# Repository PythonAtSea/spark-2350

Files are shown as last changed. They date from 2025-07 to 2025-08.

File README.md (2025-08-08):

# spark!2350

A badge of a Cerberus and a raccoon laughing together, with the text 'HIGHWAY' and 'HACK CLUB' beside them. (https://highway.hackclub.com)

## What is this?

The spark!2350 is a RP2350 based microcontroller that has a RM2 chip for BLE and WiFi. It also has a LiPo battery charger, as it is designed for use in mireless keyboards. It also has a user accesable NeoPixel, and a variable charge rate. 

## Why?

I saw the release of the RM2 and I immediatly knew I wanted to make something with it. I've always thought the nice!nano was cool, so I kinda made that, although this is designed for maximum GPIO availibility, not small size. 









made with <3 and insanity.

## BOM

| Name | Link | Price |
|---|---|---|
| RPI RM2 | https://shop.pimoroni.com/products/raspberry-pi-radio-module | $4 |
| Pimoroni shpping | n/a | $14 |
| JLC PCBA | N/A | $78.28 |
| JLC shipping | N/A | $38.52 |
| Total | N/A | $134.80 |

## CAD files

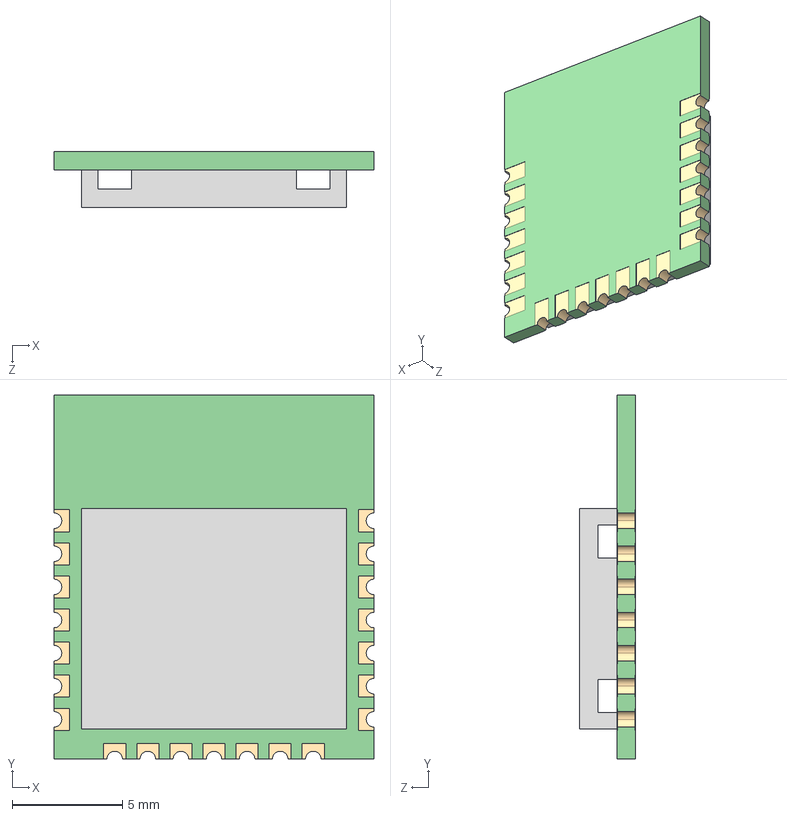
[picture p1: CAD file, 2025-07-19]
footprints/RM2/rpi_rmc20452t.step
14.5 x 16.5 x 2.55 mm

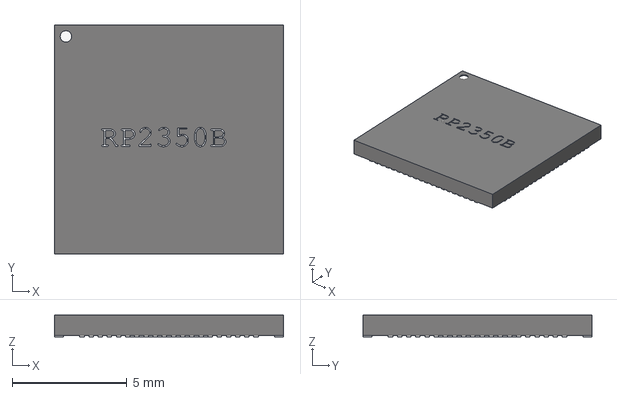
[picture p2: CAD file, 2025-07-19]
footprints/RP2350/RP2350_QFN80.step
10.0 x 10.0 x 0.95 mm

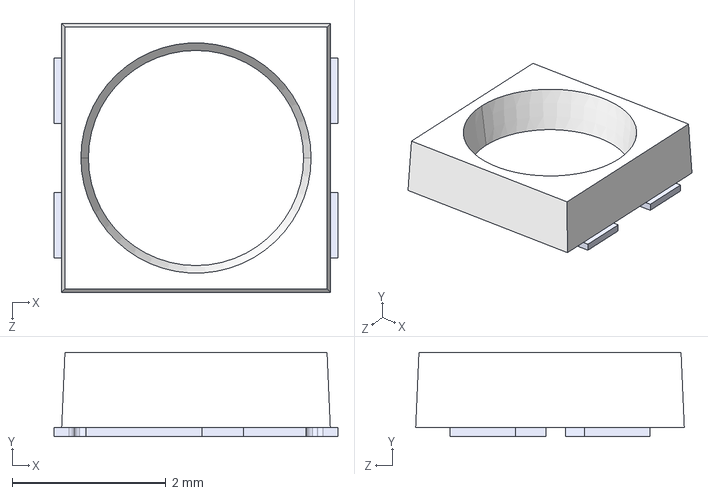
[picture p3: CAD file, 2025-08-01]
footprints/SK6812MINI-012.STEP
3.70 x 1.10 x 3.50 mm

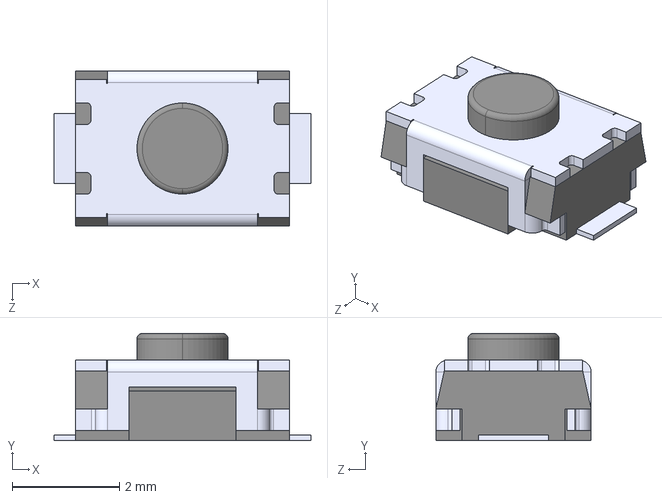
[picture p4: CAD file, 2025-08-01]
footprints/TS-1088-AR02016/TS-1088-AR02016.step
4.80 x 2.00 x 2.90 mm

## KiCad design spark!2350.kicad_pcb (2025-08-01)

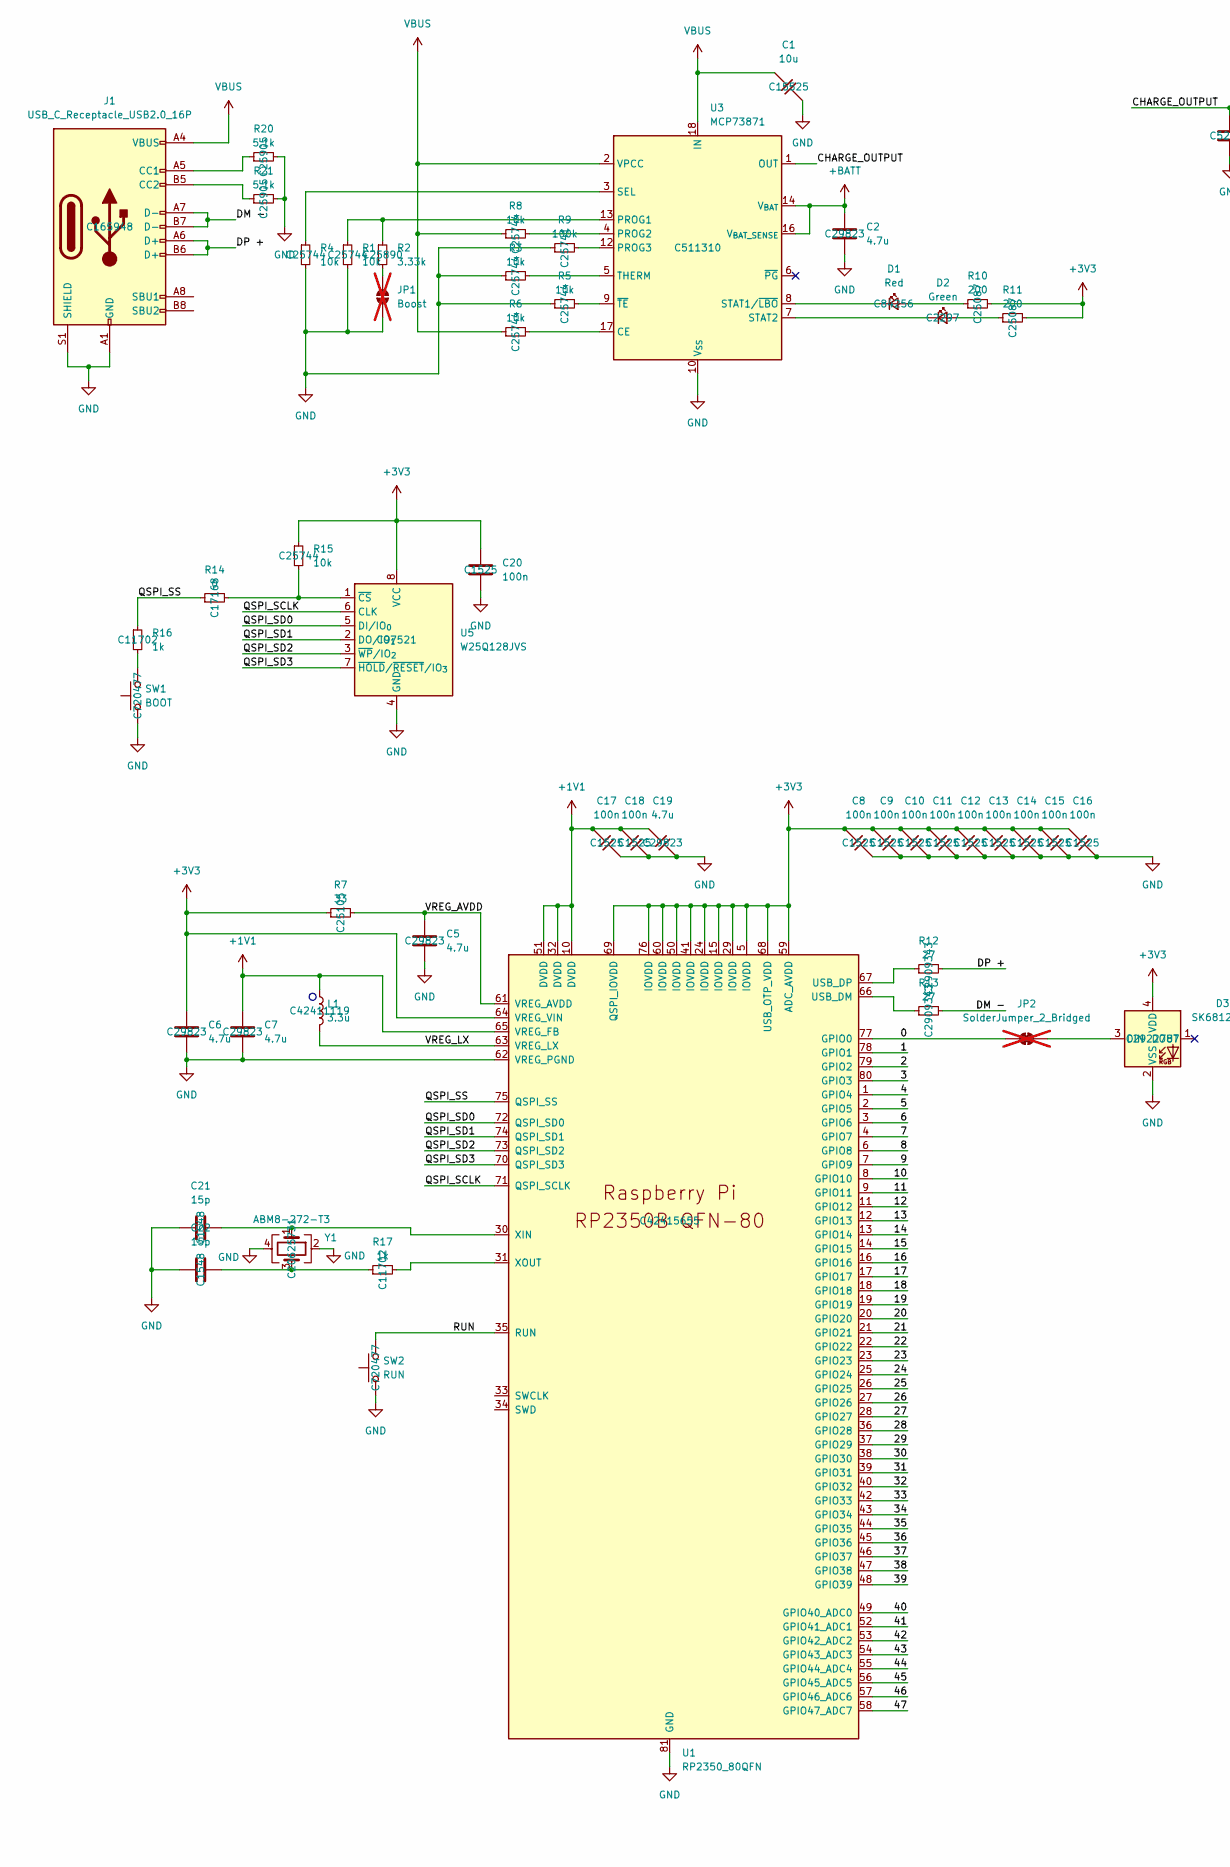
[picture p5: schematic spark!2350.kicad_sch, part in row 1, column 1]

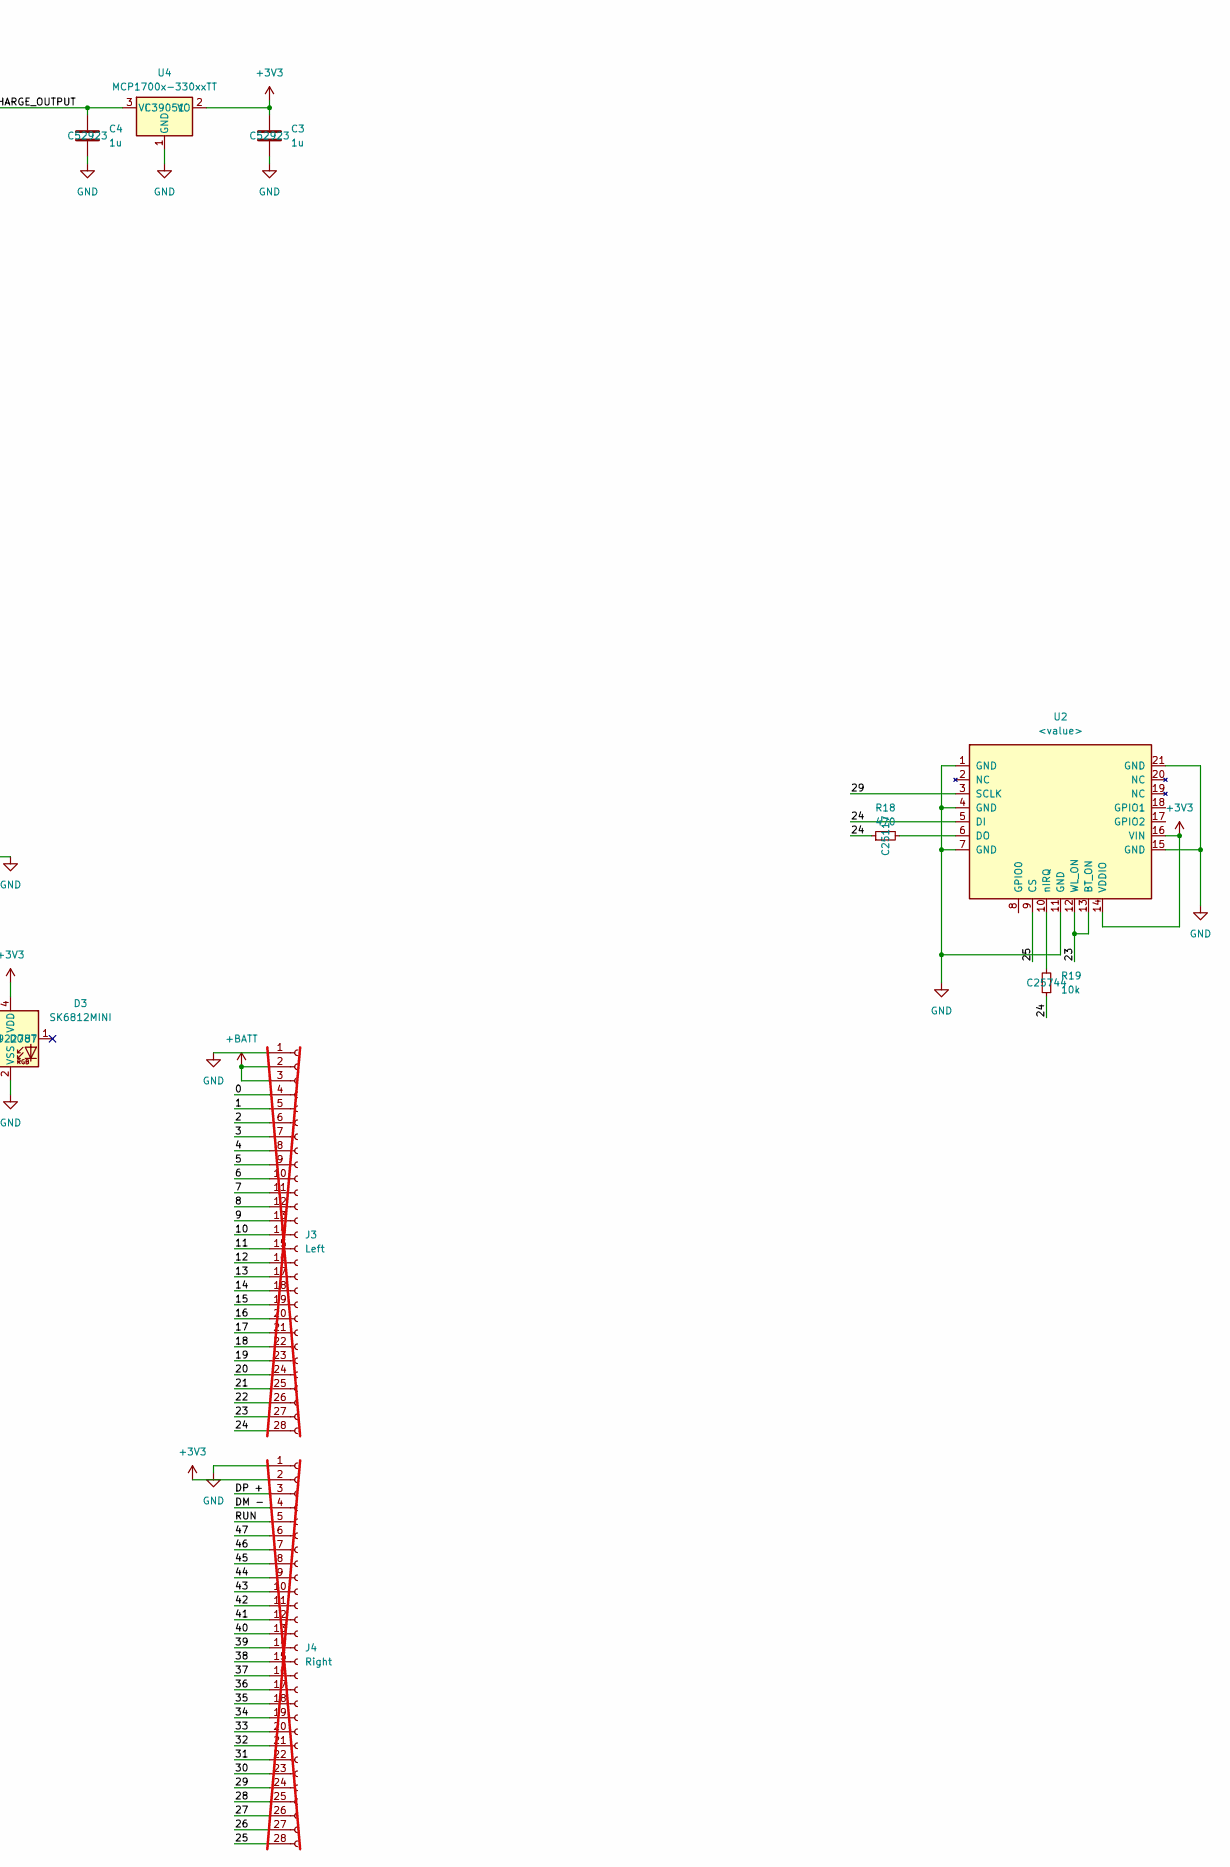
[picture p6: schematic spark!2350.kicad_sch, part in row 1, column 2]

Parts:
C1: 10u; C_0402_1005Metric_small_pads; LCSC C15525
C2, C5, C6, C7, C19: 4.7u; C_0402_1005Metric_small_pads; LCSC C29823
C3, C4: 1u; C_0402_1005Metric_small_pads; LCSC C52923
C8, C9, C10, C11, C12, C13, C14, C15, C16, C17, C18, C20: 100n; C_0402_1005Metric_small_pads; LCSC C1525
C21, C22: 15p; C_0402_1005Metric_small_pads; LCSC C1548
D1: Red; LED_0805_2012Metric; LCSC C84256
D2: Green; LED_0805_2012Metric; LCSC C2297
D3: SK6812MINI; LED_SK6812MINI_PLCC4_3.5x3.5mm_P1.75mm; LCSC C2922787
J1: USB_C_Receptacle_USB2.0_16P; USB_C_Receptacle_HRO_TYPE-C-31-M-12; LCSC C165948
J3: Left; 27right; not fitted
J4: Right; 27left; not fitted
JP1: Boost; SolderJumper-2_P1.3mm_Open_RoundedPad1.0x1.5mm; not fitted
JP2: SolderJumper_2_Bridged; SolderJumper-2_P1.3mm_Bridged_RoundedPad1.0x1.5mm; not fitted
L1: 3.3u; L_pol_2016; LCSC C42411119
R1, R3, R4, R5, R6, R8, R15, R19: 10k; R_0402_1005Metric; LCSC C25744
R2: 3.33k; R_0402_1005Metric; LCSC C25890
R7: 33; R_0402_1005Metric; LCSC C25105
R9: 100k; R_0402_1005Metric; LCSC C25741
R10, R11: 200; R_0402_1005Metric; LCSC C25087
R12, R13: 27; R_0402_1005Metric; LCSC C2909343
R14: 0; R_0402_1005Metric; LCSC C17168
R16, R17: 1k; R_0402_1005Metric; LCSC C11702
R18: 470; R_0402_1005Metric; LCSC C25117
R20, R21: 5.1k; R_0402_1005Metric; LCSC C25905
SW1: BOOT; SW_TS-1088-AR02016; LCSC C720477
SW2: RUN; SW_TS-1088-AR02016; LCSC C720477
U1: RP2350_80QFN; RP2350-QFN-80-1EP_10x10_P0.4mm_EP3.4x3.4mm_ThermalVias; LCSC C42415655
U2: <value>; rpi_rmc20452t
U3: MCP73871; QFN-20-1EP_4x4mm_P0.5mm_EP2.5x2.5mm; LCSC C511310
U4: MCP1700x-330xxTT; SOT-23; LCSC C39051
U5: W25Q128JVS; SOIC-8_5.3x5.3mm_P1.27mm; LCSC C97521
Y1: ABM8-272-T3; ABM8-272-T3_ABR; LCSC C20625731

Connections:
+1V1: C7.1, C17.2, C18.2, C19.2, L1.1, U1.10 (DVDD), U1.32 (DVDD), U1.51 (DVDD), U1.65 (VREG_FB)
+3V3: C3.1, C6.1, C8.2, C9.2, C10.2, C11.2, C12.2, C13.2, C14.2, C15.2, C16.2, C20.1, D3.4 (VDD), J4.2, R7.1, R10.2, R11.2, R15.1, U1.5 (IOVDD), U1.15 (IOVDD), U1.24 (IOVDD), U1.29 (IOVDD), U1.41 (IOVDD), U1.50 (IOVDD), U1.59 (ADC_AVDD), U1.60 (IOVDD), U1.64 (VREG_VIN), U1.68 (USB_OTP_VDD), U1.69 (QSPI_IOVDD), U1.76 (IOVDD), U2.14 (VDDIO), U2.16 (VIN), U4.2 (VO), U5.8 (VCC)
+BATT: C2.1, J3.2, J3.3, U3.14 (V_{BAT}), U3.15 (V_{BAT}), U3.16 (V_{BAT_SENSE})
/0: J3.4, JP2.1 (A), U1.77 (GPIO0)
/1: J3.5, U1.78 (GPIO1)
/2: J3.6, U1.79 (GPIO2)
/3: J3.7, U1.80 (GPIO3)
/4: J3.8, U1.1 (GPIO4)
/5: J3.9, U1.2 (GPIO5)
/6: J3.10, U1.3 (GPIO6)
/7: J3.11, U1.4 (GPIO7)
/8: J3.12, U1.6 (GPIO8)
/9: J3.13, U1.7 (GPIO9)
/10: J3.14, U1.8 (GPIO10)
/11: J3.15, U1.9 (GPIO11)
/12: J3.16, U1.11 (GPIO12)
/13: J3.17, U1.12 (GPIO13)
/14: J3.18, U1.13 (GPIO14)
/15: J3.19, U1.14 (GPIO15)
/16: J3.20, U1.16 (GPIO16)
/17: J3.21, U1.17 (GPIO17)
/18: J3.22, U1.18 (GPIO18)
/19: J3.23, U1.19 (GPIO19)
/20: J3.24, U1.20 (GPIO20)
/21: J3.25, U1.21 (GPIO21)
/22: J3.26, U1.22 (GPIO22)
/23: J3.27, U1.23 (GPIO23), U2.12 (WL_ON), U2.13 (BT_ON)
/24: J3.28, R18.1, R19.1, U1.25 (GPIO24), U2.5 (DI)
/25: J4.28, U1.26 (GPIO25), U2.9 (CS)
/26: J4.27, U1.27 (GPIO26)
/27: J4.26, U1.28 (GPIO27)
/28: J4.25, U1.36 (GPIO28)
/29: J4.24, U1.37 (GPIO29), U2.3 (SCLK)
/30: J4.23, U1.38 (GPIO30)
/31: J4.22, U1.39 (GPIO31)
/32: J4.21, U1.40 (GPIO32)
/33: J4.20, U1.42 (GPIO33)
/34: J4.19, U1.43 (GPIO34)
/35: J4.18, U1.44 (GPIO35)
/36: J4.17, U1.45 (GPIO36)
/37: J4.16, U1.46 (GPIO37)
/38: J4.15, U1.47 (GPIO38)
/39: J4.14, U1.48 (GPIO39)
/40: J4.13, U1.49 (GPIO40_ADC0)
/41: J4.12, U1.52 (GPIO41_ADC1)
/42: J4.11, U1.53 (GPIO42_ADC2)
/43: J4.10, U1.54 (GPIO43_ADC3)
/44: J4.9, U1.55 (GPIO44_ADC4)
/45: J4.8, U1.56 (GPIO45_ADC5)
/46: J4.7, U1.57 (GPIO46_ADC6)
/47: J4.6, U1.58 (GPIO47_ADC7)
/CHARGE_OUTPUT: C4.1, U3.1 (OUT), U3.20 (OUT), U4.3 (VI)
/DM -: J1.A7 (D-), J1.B7 (D-), J4.4, R13.2
/DP +: J1.A6 (D+), J1.B6 (D+), J4.3, R12.2
/QSPI_SCLK: U1.71 (QSPI_SCLK), U5.6 (CLK)
/QSPI_SD0: U1.72 (QSPI_SD0), U5.5 (DI/IO_{0})
/QSPI_SD1: U1.74 (QSPI_SD1), U5.2 (DO/IO_{1})
/QSPI_SD2: U1.73 (QSPI_SD2), U5.3 (~WP/IO_{2})
/QSPI_SD3: U1.70 (QSPI_SD3), U5.7 (~HOLD/~RESET/IO_{3})
/QSPI_SS: R14.1, R16.1, U1.75 (QSPI_SS)
/RUN: J4.5, SW2.2, U1.35 (RUN)
/VREG_AVDD: C5.1, R7.2, U1.61 (VREG_AVDD)
/VREG_LX: L1.2, U1.63 (VREG_LX)
GND: C1.1, C2.2, C3.2, C4.2, C5.2, C6.2, C7.2, C8.1, C9.1, C10.1, C11.1, C12.1, C13.1, C14.1, C15.1, C16.1, C17.1, C18.1, C19.1, C20.2, C21.1, C22.1, D3.2 (VSS), J1.A1 (GND), J1.A12 (GND), J1.B1 (GND), J1.B12 (GND), J1.S1 (SHIELD), J3.1, J4.1, JP1.1 (A), R1.2, R3.1, R4.2, R5.1, R9.1, R20.2, R21.2, SW1.1, SW2.1, U1.62 (VREG_PGND), U1.81 (GND), U2.1 (GND), U2.4 (GND), U2.7 (GND), U2.11 (GND), U2.15 (GND), U2.21 (GND), U3.10 (V_{SS}), U3.11 (V_{SS}), U3.21 (V_{SS}), U4.1 (GND), U5.4 (GND), Y1.2, Y1.4
unnamed: C22.2, R17.1, Y1.3
unnamed: D1.2 (A), R10.1
unnamed: D1.1 (K), U3.8 (STAT1/~LBO)
unnamed: D2.2 (A), R11.1
unnamed: D2.1 (K), U3.7 (STAT2)
unnamed: D3.3 (DIN), JP2.2 (B)
unnamed: J1.A5 (CC1), R20.1
unnamed: J1.B5 (CC2), R21.1
unnamed: JP1.2 (B), R2.2
unnamed: R16.2, SW1.2
unnamed: R13.1, U1.66 (USB_DM)
unnamed: R12.1, U1.67 (USB_DP)
unnamed: C21.2, U1.30 (XIN), Y1.1
unnamed: R17.2, U1.31 (XOUT)
unnamed: R18.2, U2.6 (DO)
unnamed: R19.2, U2.10 (nIRQ)
unnamed: R6.2, U3.17 (CE)
unnamed: R1.1, R2.1, U3.13 (PROG1)
unnamed: R8.2, U3.4 (PROG2)
unnamed: R9.2, U3.12 (PROG3)
unnamed: R4.1, U3.3 (SEL)
unnamed: R3.2, U3.5 (THERM)
unnamed: R5.2, U3.9 (~TE)
unnamed: R14.2, R15.2, U5.1 (~CS)
VBUS: C1.2, J1.A4 (VBUS), J1.A9 (VBUS), J1.B4 (VBUS), J1.B9 (VBUS), R6.1, R8.1, U3.2 (VPCC), U3.18 (IN), U3.19 (IN)

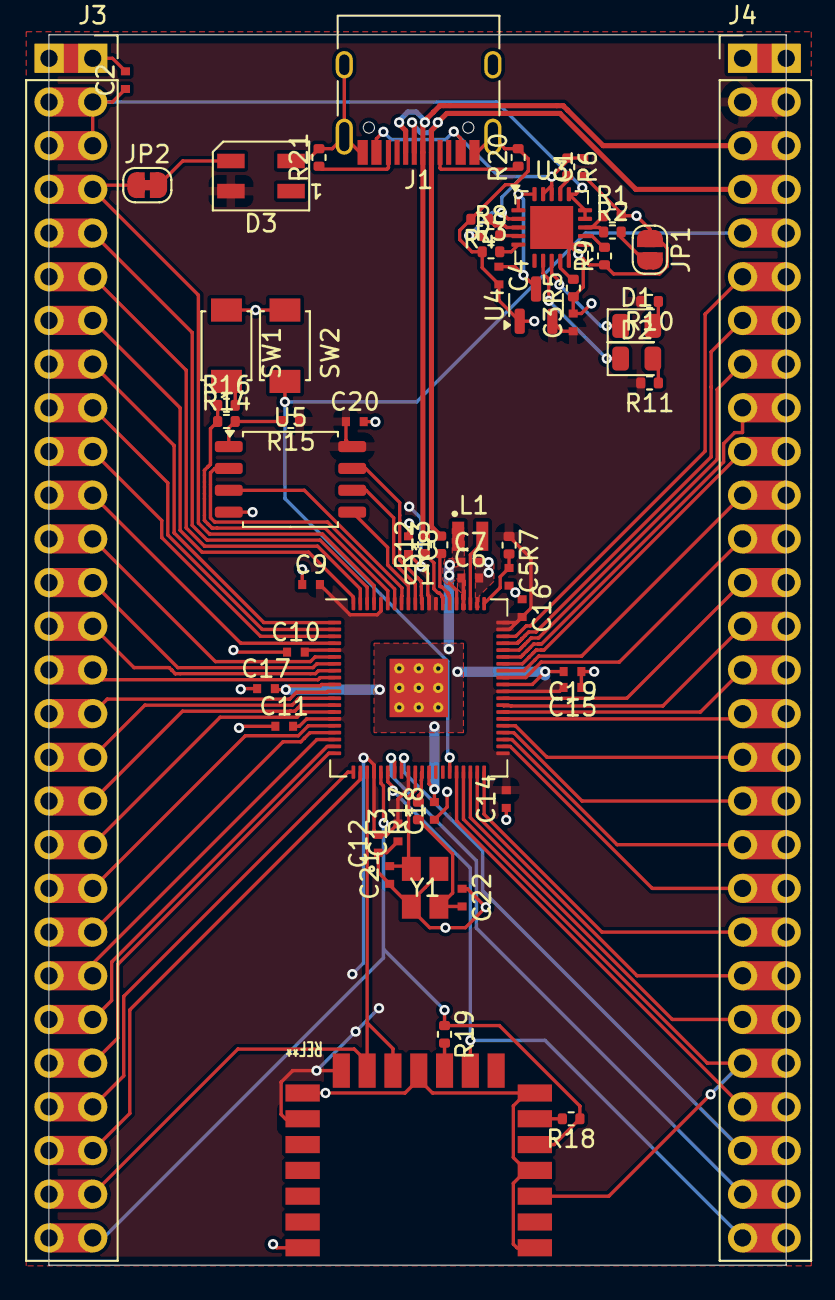
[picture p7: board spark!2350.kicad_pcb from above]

Board: 2 copper layers, 42.9 x 71.5 mm, 60 parts (0 on the bottom side), 89 nets.

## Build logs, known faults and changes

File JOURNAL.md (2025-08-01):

---
title: "spark!2350"
author: "Hudson / pythonatsea"
description: "nice!nano but RP2350"
created_at: "2024-07-18"
---

# spark!2350, total hours: ***24***

## 7/18/25, 3 hours

### Basic idea

Basically I'm making a rp2350 based MCU designed fo keyboards, with a intergrated LiPo charger and a RPI RM2 for BLE. I'm also planning to have a intergrated rgb led, and maybe a OLED screen.

### Charger circuit.

I'm using the [MCP73871](https://www.microchip.com/en-us/product/MCP73871) to both charge the battery and switch between USB nd battery power. It uses a resistor pulldown to the PROG1 pin to set the charge current, which allows for some cool stuff. Using a little bit of math, I was able to calculate resistor values such that if you connect a solder jumper, the charge current changes from 100mA to 400mA. (this was inspired by the nice!nano v2's thing, which does the exact same thing!)



## 7/21/25, 5 hours

### Power supply

Since I'm using a battery charger, the voltage regulator can receive 3.7-4.2v (from the battery) or it can get the 5v passed through from the usb port. This means it has to have >300mA of dropoff, which means the one recommended by the rp2350 design guide won't actually work, since it has ~1v of dropoff. I was able to find the MCP1700, which has ~250mA of dropoff, which works perfectly!



### Flash

I'm using the W25Q128JVS flash, which is the recommended module from the design guide. It has 128 mbits of storage, the max allowable, and it's also a basic part on JLC!

### Crystal

Again, I'm just going with the recommended module, but here it's more important than the flash, as the crystal has to be very precise for stuff like USB to work.



## 7/27/25, 4 hours

### Pinout

I made the pinout for the left and right pinheaders, it has the USB data pins broken out so that the user can have their own USB port if they desire.



### NeoPixel

I put a neopixel on `GPIO0`, with a jumper that can be cut so the pin can be used for other things.



### Schematic (mostly) done!

The schematic is done, now I need to find footprints and make the actual PCB!!

## 7/29/25, 4 hours

### Footprints (sigh)

I had to find a bunch of different footprints, including the RP2350, the inductor, and the crystal. I also had to make a castellated hole footprint, which worked quite well. 



### General layout

The two castellated headers are positioned so they have 25mm between them. The antenna of the RM2 hangs of the bottom of the PCB so that there's no copper in the RF keepout.



## 7/31/25, 8 hours (oh boy i locked in)

### Parts

I'm trying to use as many basic/preferred extended parts as possible to keep costs low. For example, I'm using relativly large 0805 LEDs for the charging indicators because they're basic parts.

### Routing

Imma be honest, there was a lot of wacky nonsense that took a while to fix but I don't really remeber specifics. Actually I did switch USBC posrt because routing would've been close to immpossible with the other one because of the two d+ and d- pins being on opposite sides. 



### Finished!

It's finally done! I'm pretty happy with hor it turned out, if I had to make a v2 I'd probably try to make it smaller.



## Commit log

2025-07-19 first commit!
    [RP2350_QFN80.step, rpi_rmc20452t.step, spark!2350.kicad_pcb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]
2025-07-30 pcb started yay!
2025-08-01 i kinda forgot to bump hardware files regularly so here ya go!
    [SK6812MINI-012.STEP, TS-1088-AR02016.step, spark!2350.kicad_pcb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]
2025-08-01 schematic :facepalm:
